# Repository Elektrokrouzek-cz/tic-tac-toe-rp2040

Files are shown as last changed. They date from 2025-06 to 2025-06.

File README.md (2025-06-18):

# Tic-tac-toe based on RP2040
This is the construction of tic-tac-toe game based on Raspberry Pi Pico (RP2040). It consists of 3x3 game layout with Neopixel 5mm LEDs and buttons.

Code is written in Micropython

PCB is 2-layer and was designed using KiCad 9. Fabrication output for JLCPCB is in gerber folder.

**Happy coldering and coding**

Assembled PCB

Assembled PCB


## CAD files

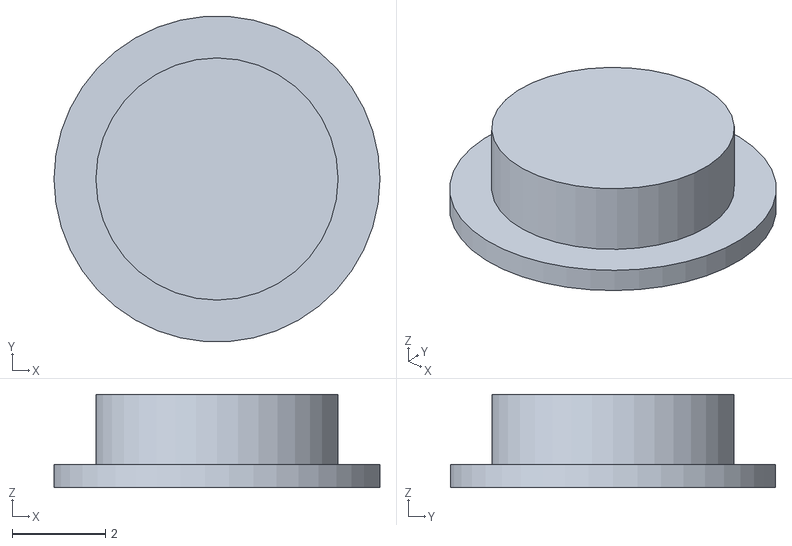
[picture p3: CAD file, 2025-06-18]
3d/tic_tac_toe_player_window.stl
7.00 x 6.98 x 2.00

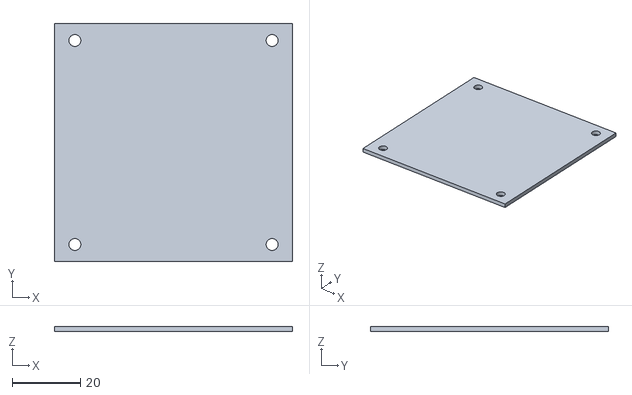
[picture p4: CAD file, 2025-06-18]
3d/tic_tac_toe_back_cover.stl
70.0 x 70.0 x 1.60

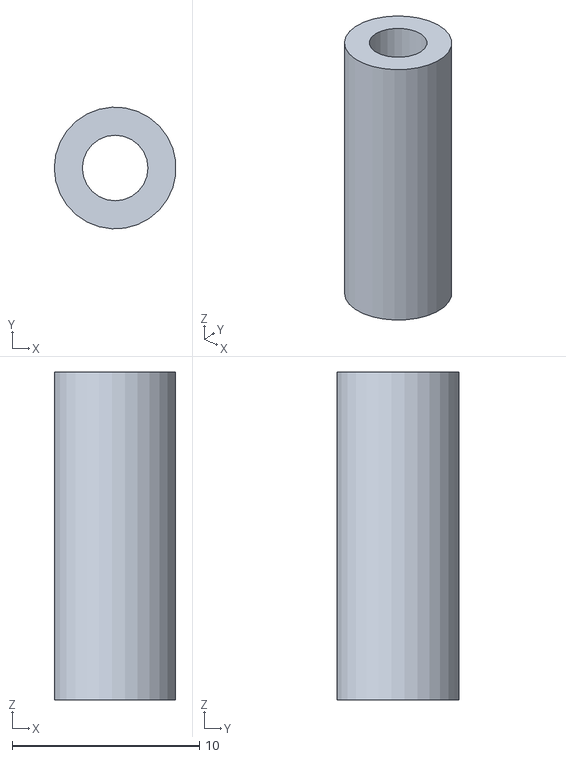
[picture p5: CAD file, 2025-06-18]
3d/tic_tac_toe_spacer.stl
6.48 x 6.49 x 17.5

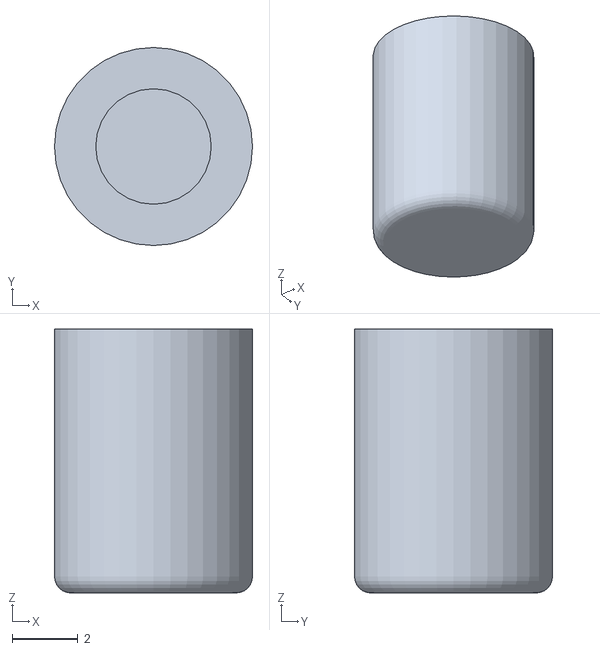
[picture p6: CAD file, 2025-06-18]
3d/tic_tac_toe_button.stl
6.00 x 6.00 x 8.00

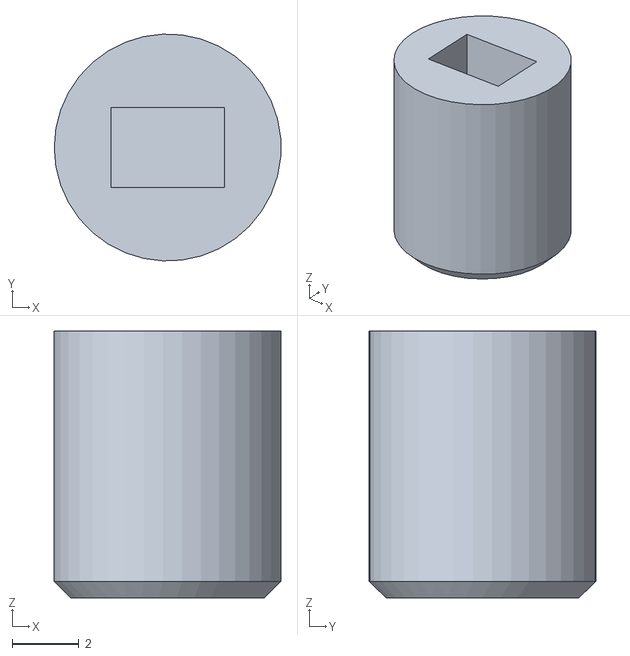
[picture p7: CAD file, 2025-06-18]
3d/tic_tac_toe_switch.stl
6.79 x 6.79 x 8.00

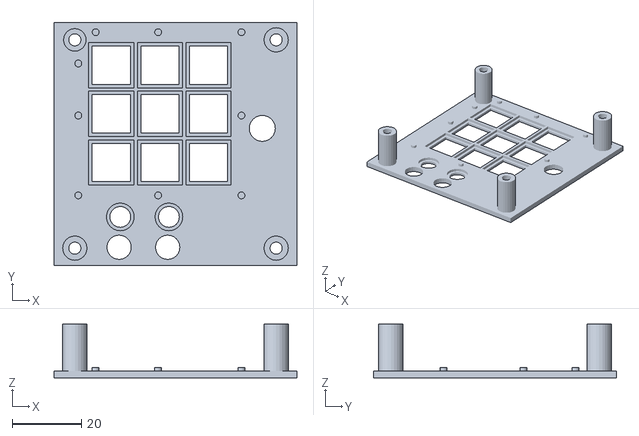
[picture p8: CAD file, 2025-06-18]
3d/tic_tac_toe_front_cover.stl
70.0 x 70.0 x 15.5

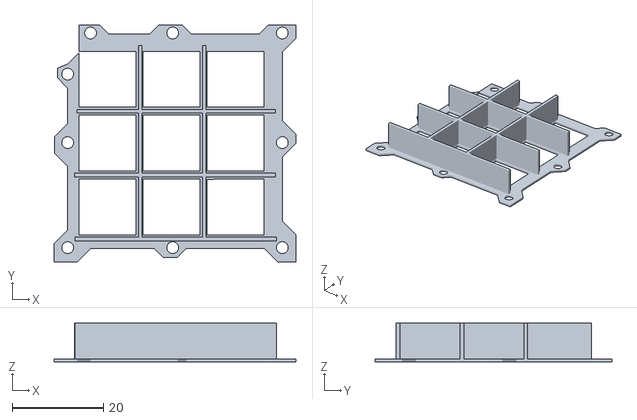
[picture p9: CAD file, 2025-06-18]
3d/tic_tac_toe_button_holder.stl
53.0 x 52.0 x 8.50

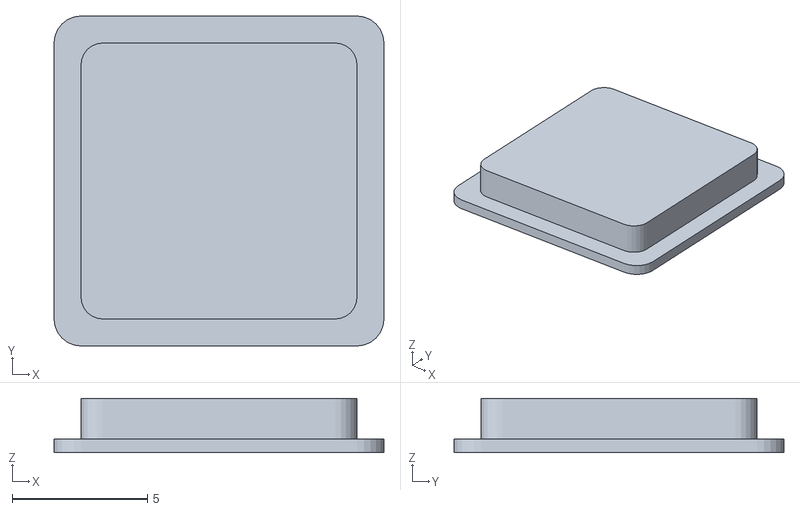
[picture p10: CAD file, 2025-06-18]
3d/tic_tac_toe_button_window.stl
12.2 x 12.2 x 2.00

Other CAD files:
3d/tic_tac_toe.f3d

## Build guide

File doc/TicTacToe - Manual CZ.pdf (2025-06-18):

www.elektrokrouzek.cz

## Piškvorky s RP2040

## Popis zapojení

Tato konstrukce je jednoduchá hra piškvorky, založená na Raspberry Pi Pico (RP2040 modul). Matice 3x3 Neopixel RGB LED diod, zapojených do řetězu, je připojena do GPIO0 pinu. Herní tlačítka jsou zapojena jako 3x3 matice se 3 sloupci and 3 řádky.
Další řetěz dvou Neopixel LED je zapojen do GPIO1 pinu. Dvě tlačítka pro volbu hráčů jsou zapojena do GPIO2 a GPIO3 pinů.
Hra může být napájena z USB nebo ze 4 AAA baterií. Je použit DC-DC step-down měnič pro vytvoření 5V napájení. Pro oddělení napájení USB od baterií je použita Schottkyho dioda.

## Popis sestavení

Začneme rezistory, dále Schottkyho diodou, RP2040 modulem a DC-DC step-down měničem. Následně osadíme tranzistor, LED diody, piezo, svorkovnici, tlačítka a vypínač.

## Oživení

Pokud jste pracovali pečlivě mělo by zapojení fungovat na první pokus. Je nutné do modulu RP2040 uložit firmware. Můžete použít např. Thonny IDE. Zdrojový kód je v git repozitáři.

## Seznam součástek

Annotation | Type | Qty
BZ1 | Passive buzzer | 1
D1,D2,D3,D4,D5,D6,D7,D8,D9,D10,D11 | APA-106-F5 | 11
D12 | BAT85 | 1
J1 | Screw terminal 3.5mm | 1
Q1 | BC546 | 1
R1 | 100k | 1
R2 | 10k | 1
SW1,SW2,SW3,SW4,SW5,SW6,SW7,SW8,SW9,SW10,SW11 | Turbo switch 7x7 | 11
SW12 | 7x7mm button | 1
U1 | WaveShare RP2040 | 1
U2 | DC-DC | 1

## Orientace vypínače a osazení desky

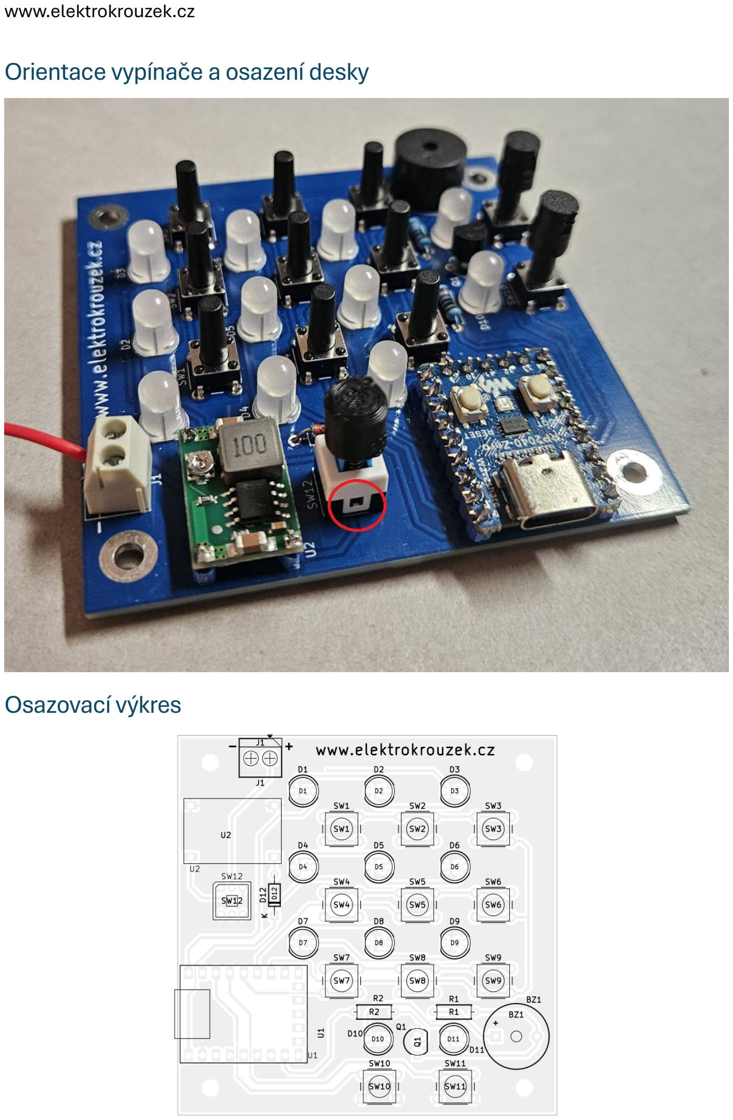
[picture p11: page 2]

## Osazovací výkres

## Mechanické sestavení

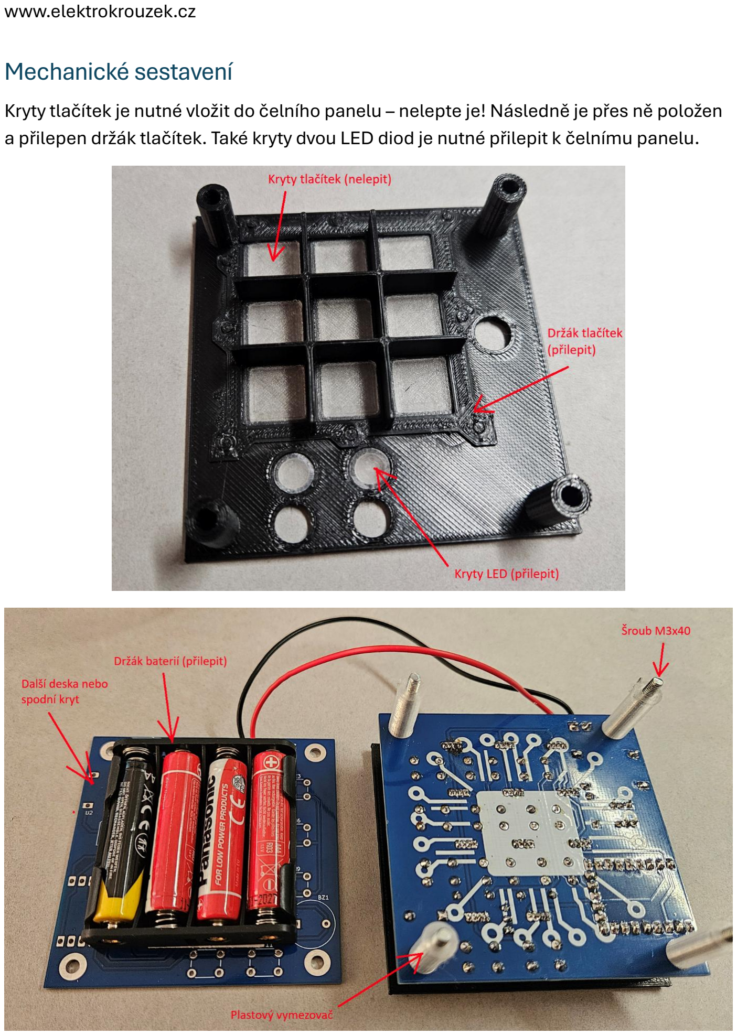
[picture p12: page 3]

Kryty tlačítek je nutné vložit do čelního panelu – nelepte je! Následně je přes ně položen a přilepen držák tlačítek. Také kryty dvou LED diod je nutné přilepit k čelnímu panelu.

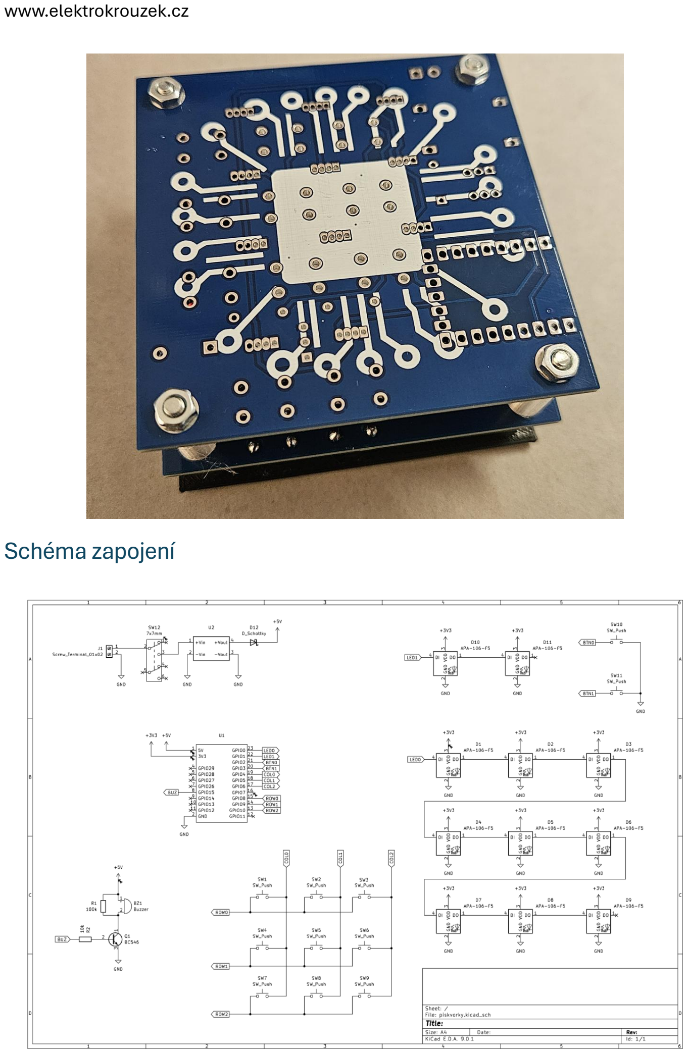
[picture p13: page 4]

## Schéma zapojení

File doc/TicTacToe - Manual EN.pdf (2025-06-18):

www.elektrokrouzek.cz

## Tic-tac-toe with RP2040

## Schematic description

This construction is the simple tic-tac-toe game based on Raspberry Pi Pico (RP2040 module). The matrix of 3x3 Neopixel RGB LED chain is connected to GPIO0 pin. Play buttons are connected as 3x3 matrix with 3 columns and 3 rows.
Another 2 Neopixel LED chain is connected to GPIO1 pin. 2 buttons for player selection are connected to GPIO2 and GPIO3 pins.
Game can be powered from USB or from 4 AAA batteries. DC-DC step-down is used to achieve 5V power supply. Schottky diode is used to separate USB and battery power supply.

## Construction

Resistors shall be populated first, then Schottky diode, RP2040 module and DC-DC step-down module. Then we populate transistor, LEDS, buzzer, terminal, buttons and power switch.

## How to get it into service

It should work on the first try when everything was soldered well. Firmware shall be saved to RP2040. You can use e.g. Thonny IDE. Source code can be found in git
repository.

## Bill of materials

Annotation | Type | Qty
BZ1 | Passive buzzer | 1
D1,D2,D3,D4,D5,D6,D7,D8,D9,D10,D11 | APA-106-F5 | 11
D12 | BAT85 | 1
J1 | Screw terminal 3.5mm | 1
Q1 | BC546 | 1
R1 | 100k | 1
R2 | 10k | 1
SW1,SW2,SW3,SW4,SW5,SW6,SW7,SW8,SW9,SW10,SW11 | Turbo switch 7x7 | 11
SW12 | 7x7mm button | 1
U1 | WaveShare RP2040 | 1
U2 | DC-DC | 1

## Button orientation and board assembly

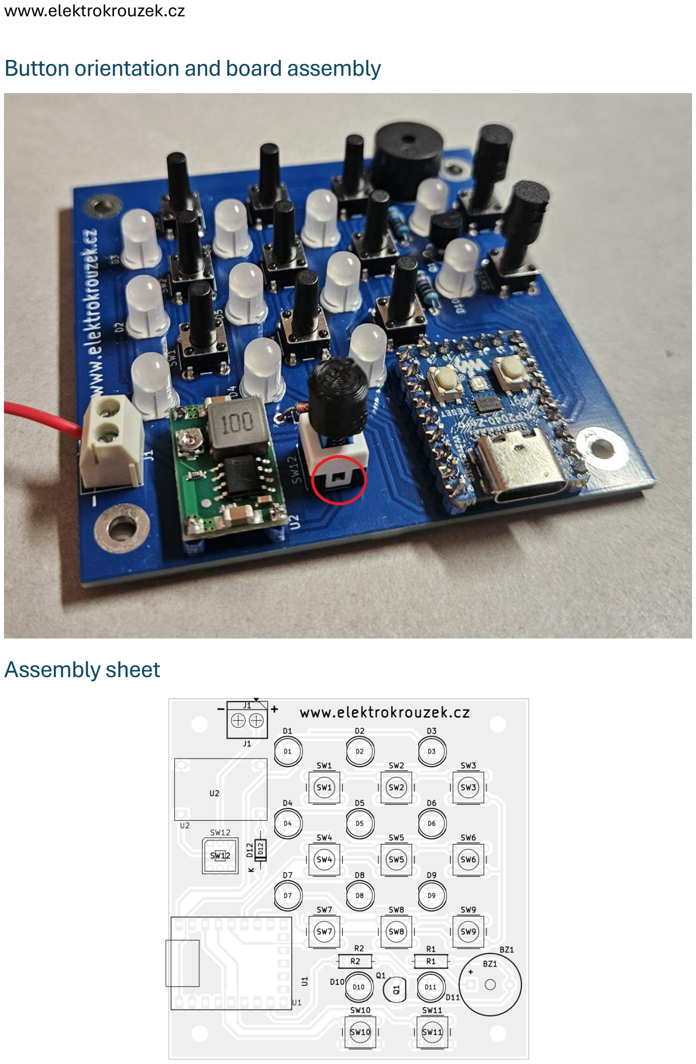
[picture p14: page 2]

## Assembly sheet

## Mechanical assembly

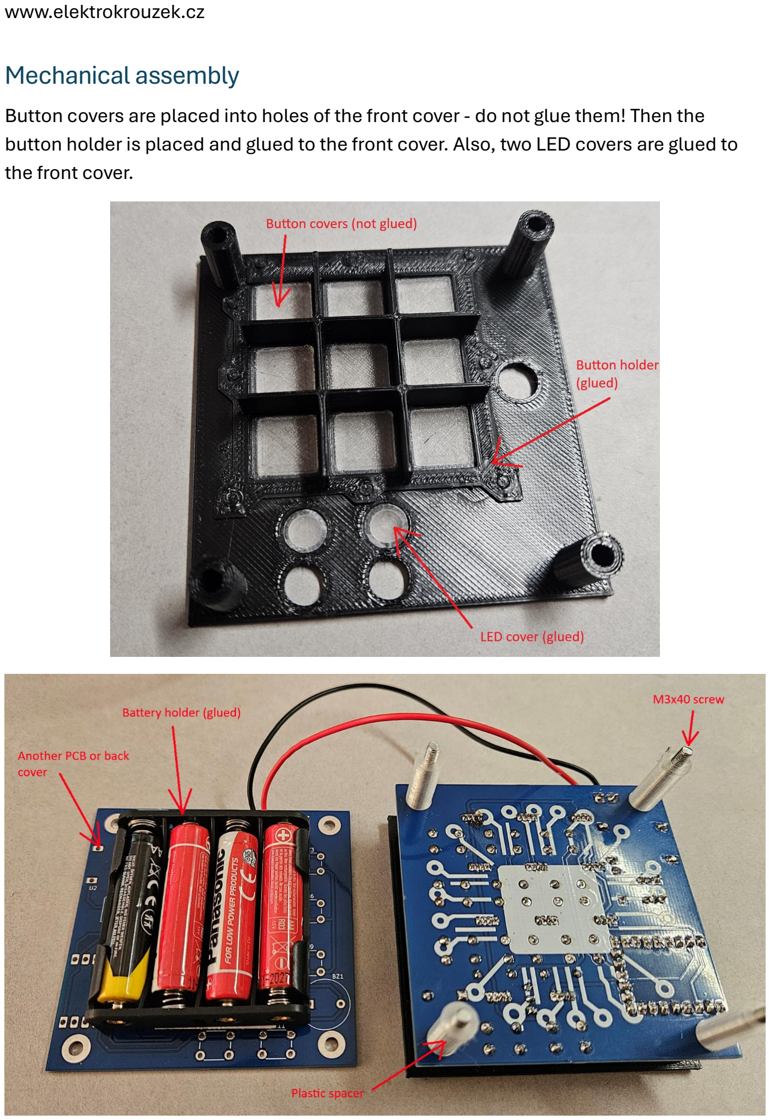
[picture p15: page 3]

Button covers are placed into holes of the front cover - do not glue them! Then the button holder is placed and glued to the front cover. Also, two LED covers are glued to the front cover.

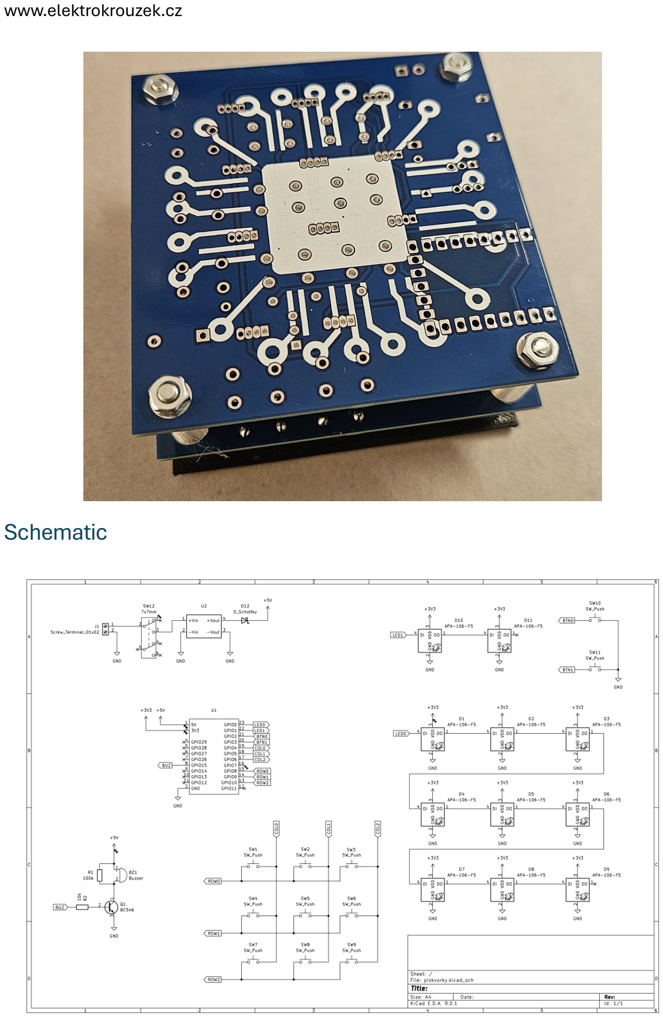
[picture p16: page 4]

## Schematic

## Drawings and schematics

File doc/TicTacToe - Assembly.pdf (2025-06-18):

1 | 2 | 3 | 4 | 5 | 6

A

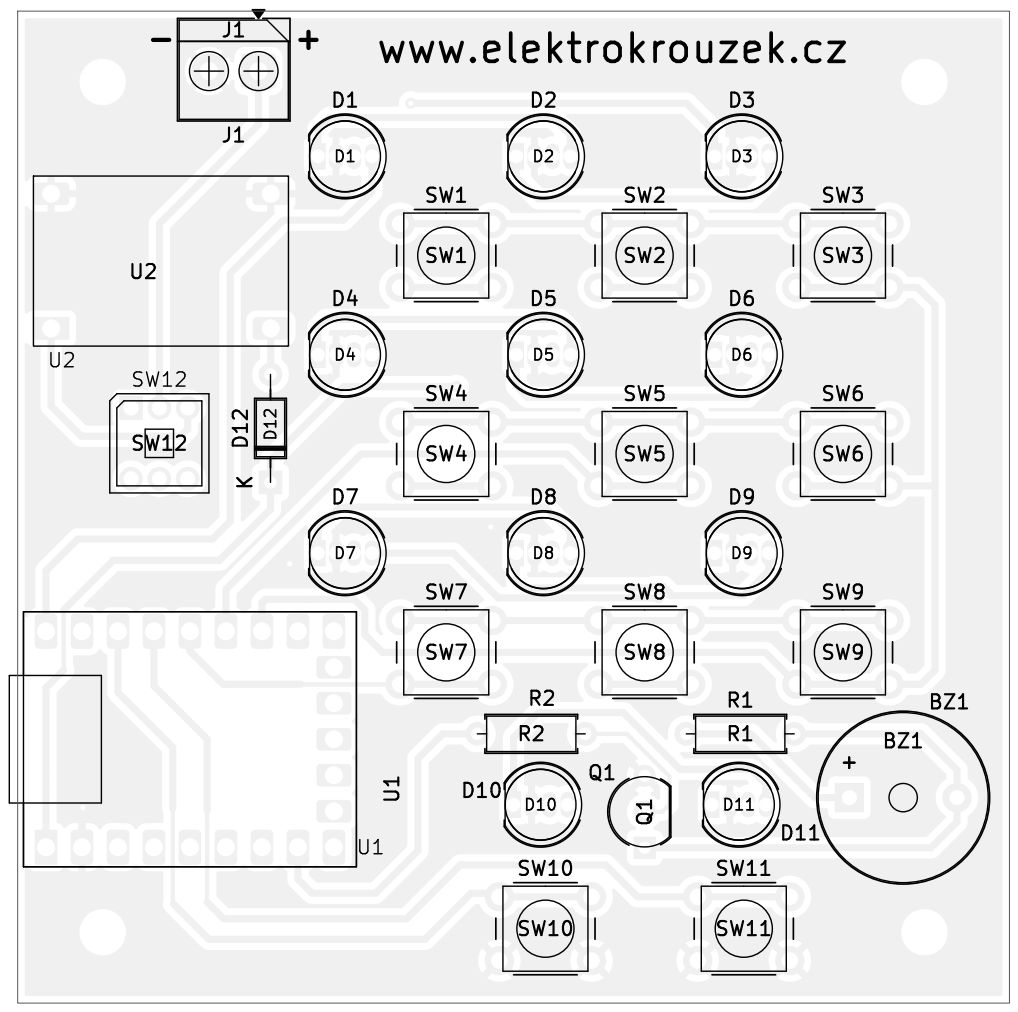
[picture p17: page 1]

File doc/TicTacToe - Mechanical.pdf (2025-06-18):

11.75 5.25 1 | 2 | 3 | 4 | 5 | 6

A

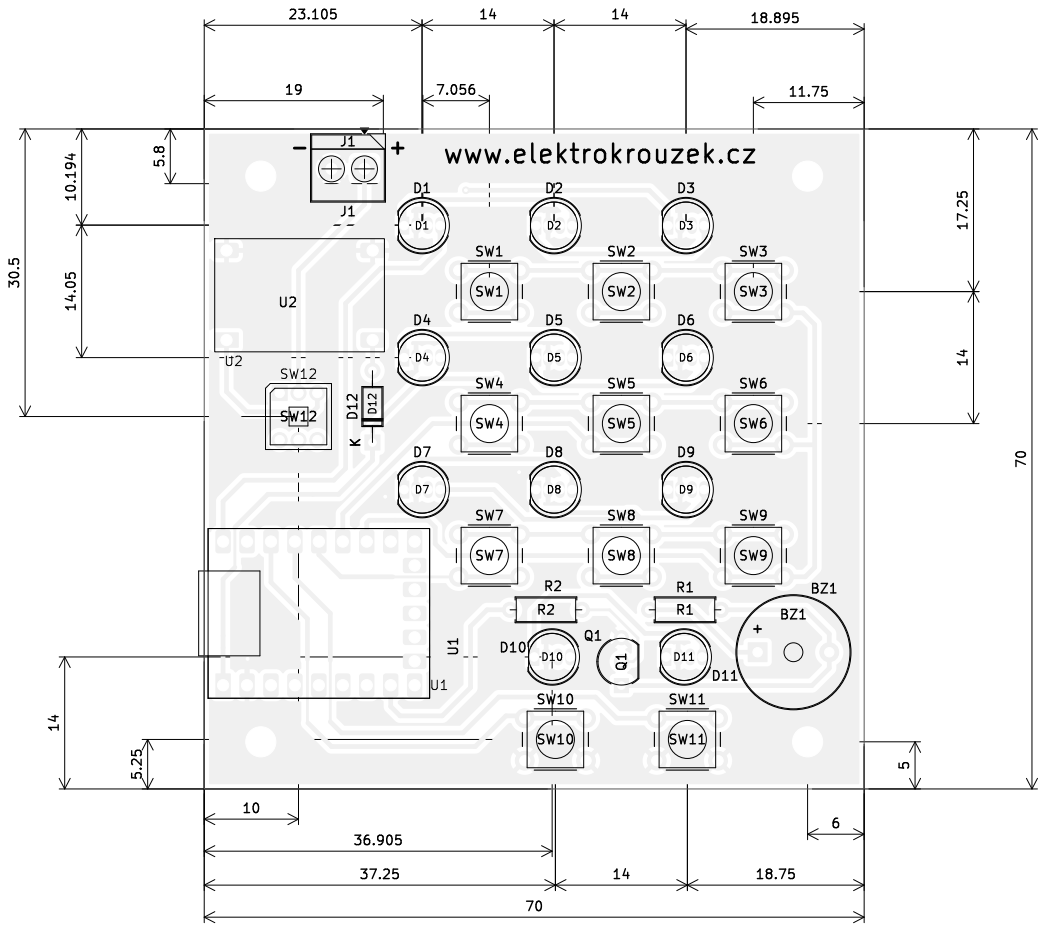
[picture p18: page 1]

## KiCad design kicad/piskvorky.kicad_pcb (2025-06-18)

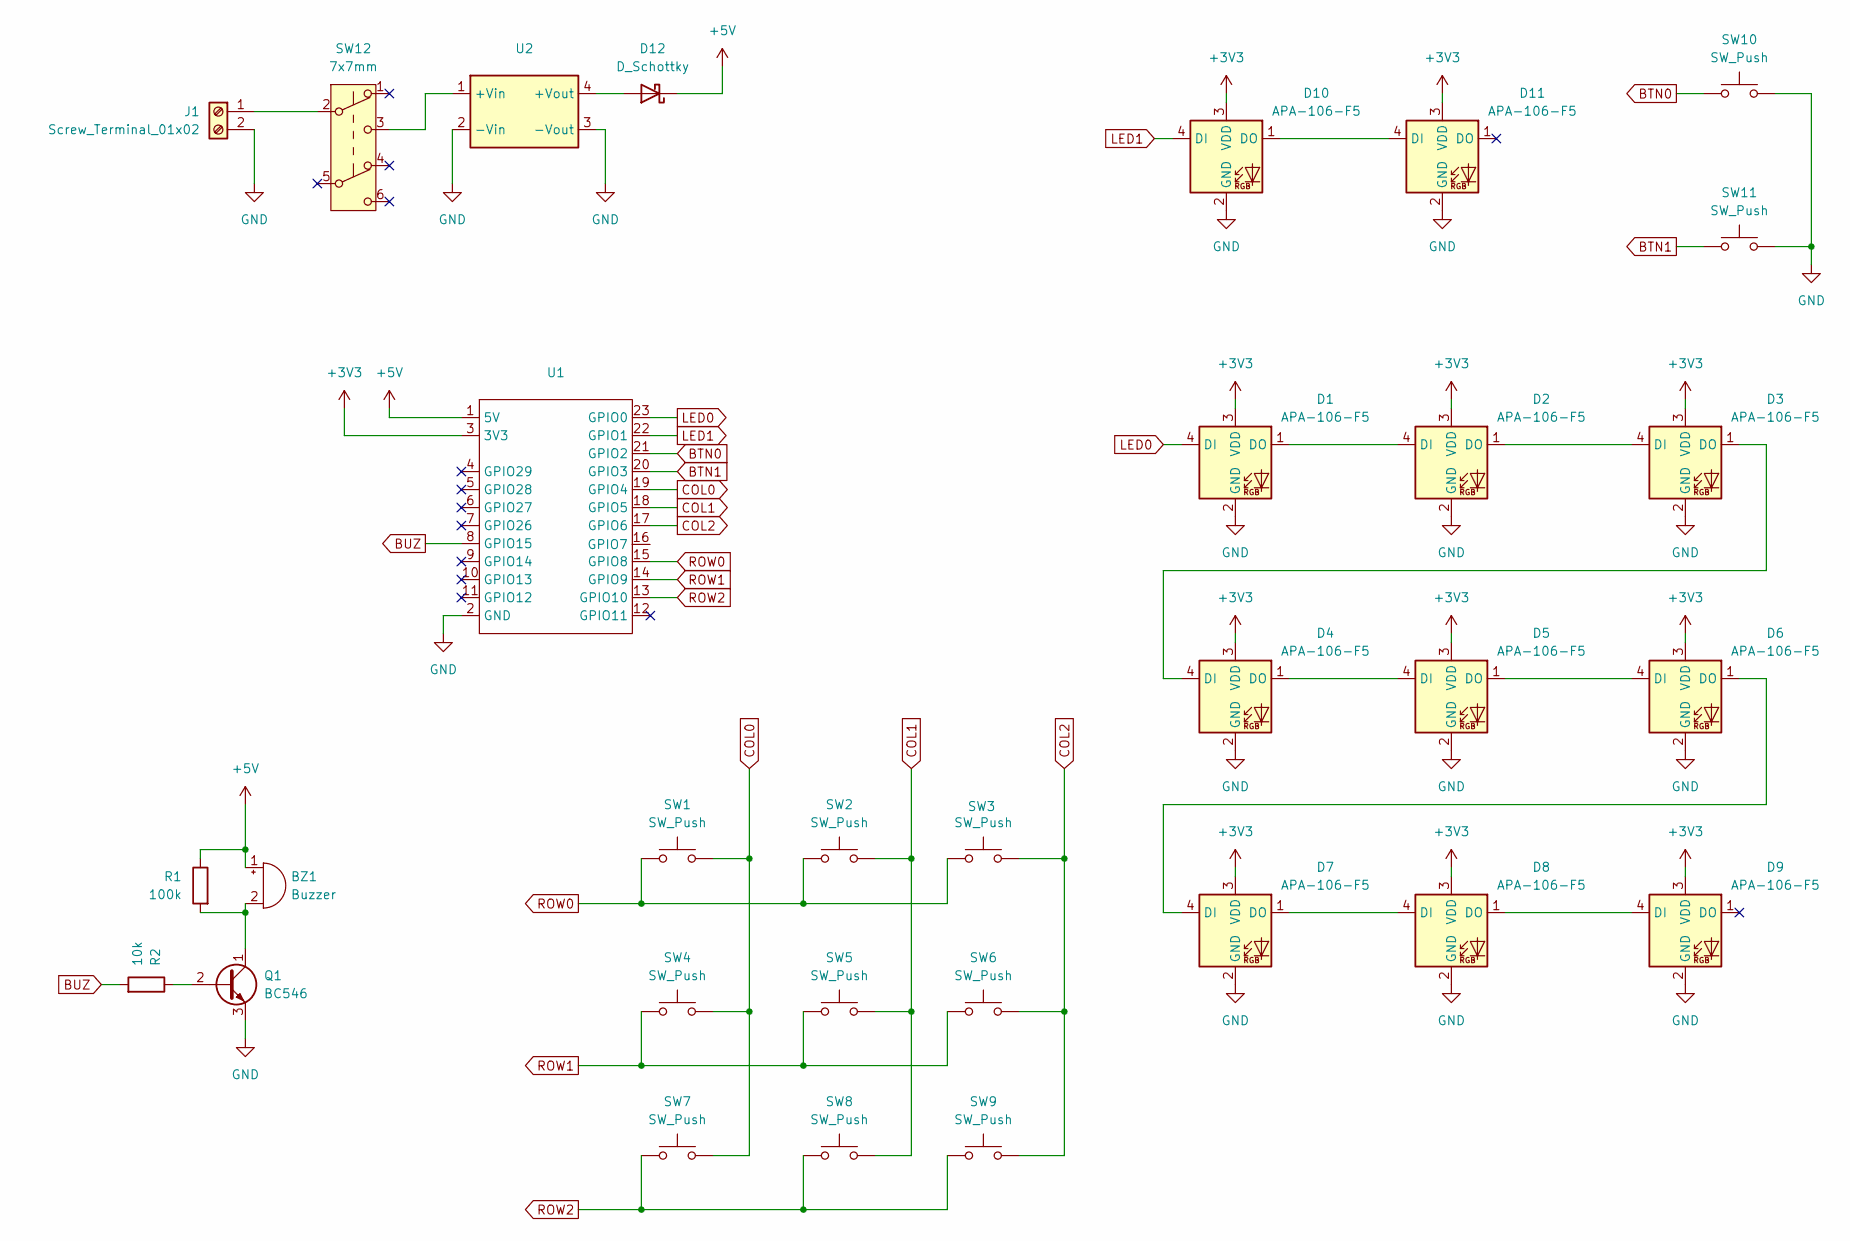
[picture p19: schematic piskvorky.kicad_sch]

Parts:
BZ1: Buzzer; Buzzer_12x9.5RM7.6
D1, D2, D3, D4, D5, D6, D7, D8, D9, D10, D11: APA-106-F5; LED_D5.0mm-4_RGB
D12: D_Schottky; D_DO-35_SOD27_P7.62mm_Horizontal
J1: Screw_Terminal_01x02; TerminalBlock_4Ucon_1x02_P3.50mm_Horizontal
Q1: BC546; TO-92_Inline_Wide
R1: 100k; R_Axial_DIN0207_L6.3mm_D2.5mm_P7.62mm_Horizontal
R2: 10k; R_Axial_DIN0207_L6.3mm_D2.5mm_P7.62mm_Horizontal
SW1, SW2, SW3, SW4, SW5, SW6, SW7, SW8, SW9, SW10, SW11: SW_Push; SW_PUSH_6mm_H5mm
SW12: 7x7mm; SW_DPDT_7x7_Turbo
U1: Waveshare RP2040
U2: DC-DC-18x12mm

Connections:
+3V3: D1.3 (VDD), D2.3 (VDD), D3.3 (VDD), D4.3 (VDD), D5.3 (VDD), D6.3 (VDD), D7.3 (VDD), D8.3 (VDD), D9.3 (VDD), D10.3 (VDD), D11.3 (VDD), U1.3 (3V3)
+5V: BZ1.1 (+), D12.1 (K), R1.1, U1.1 (5V)
BTN0: SW10.1, U1.21 (GPIO2)
BTN1: SW11.1, U1.20 (GPIO3)
BUZ: R2.2, U1.8 (GPIO15)
COL0: SW1.2, SW4.2, SW7.2, U1.19 (GPIO4)
COL1: SW2.2, SW5.2, SW8.2, U1.18 (GPIO5)
COL2: SW3.2, SW6.2, SW9.2, U1.17 (GPIO6)
GND: D1.2 (GND), D2.2 (GND), D3.2 (GND), D4.2 (GND), D5.2 (GND), D6.2 (GND), D7.2 (GND), D8.2 (GND), D9.2 (GND), D10.2 (GND), D11.2 (GND), J1.2, Q1.3 (E), SW10.2, SW11.2, U1.2 (GND), U2.2 (-Vin), U2.3 (-Vout)
LED0: D1.4 (DI), U1.23 (GPIO0)
LED1: D10.4 (DI), U1.22 (GPIO1)
unnamed: BZ1.2 (-), Q1.1 (C), R1.2
unnamed: D1.1 (DO), D2.4 (DI)
unnamed: D2.1 (DO), D3.4 (DI)
unnamed: D3.1 (DO), D4.4 (DI)
unnamed: D4.1 (DO), D5.4 (DI)
unnamed: D5.1 (DO), D6.4 (DI)
unnamed: D6.1 (DO), D7.4 (DI)
unnamed: D7.1 (DO), D8.4 (DI)
unnamed: D8.1 (DO), D9.4 (DI)
unnamed: D10.1 (DO), D11.4 (DI)
unnamed: D12.2 (A), U2.4 (+Vout)
unnamed: J1.1, SW12.2 (B)
unnamed: Q1.2 (B), R2.1
unnamed: SW12.3 (C), U2.1 (+Vin)
ROW0: SW1.1, SW2.1, SW3.1, U1.15 (GPIO8)
ROW1: SW4.1, SW5.1, SW6.1, U1.14 (GPIO9)
ROW2: SW7.1, SW8.1, SW9.1, U1.13 (GPIO10)

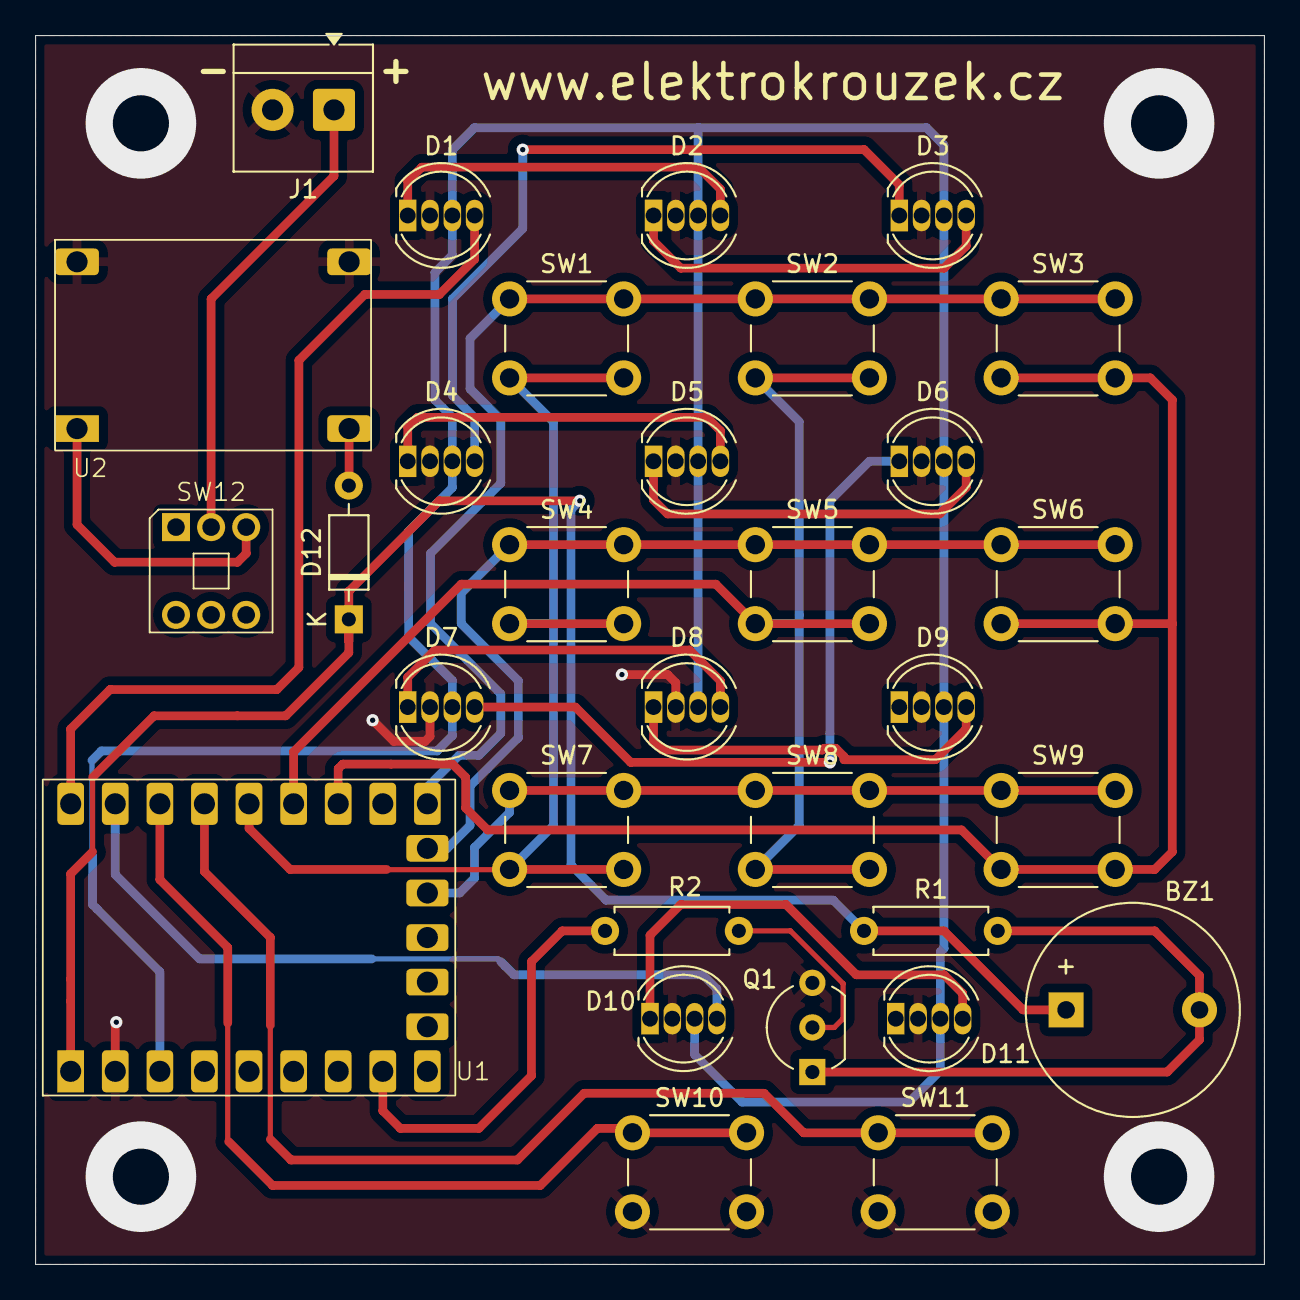
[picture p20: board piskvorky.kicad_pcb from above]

Board: 2 copper layers, 70.0 x 70.0 mm, 31 parts (0 on the bottom side), 28 nets.

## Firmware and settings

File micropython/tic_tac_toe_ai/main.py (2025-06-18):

import time
import machine, neopixel

WIDTH = 3
HEIGHT = 3

COLOR_NONE = 0
COLOR_RED = 1
COLOR_GREEN = 2
COLOR_BLUE = 3
COLOR_RED_REMOVE = 4
COLOR_GREEN_REMOVE = 5

COLOR_PLAYER1 = COLOR_RED
COLOR_PLAYER1_REMOVE = COLOR_RED_REMOVE
COLOR_PLAYER2 = COLOR_GREEN
COLOR_PLAYER2_REMOVE = COLOR_GREEN_REMOVE

KEY_DOWN_TIME = 0.05
    

class Screen:

    PROCESS_BLINK_PLAYER = 0
    PROCESS_BLINK_REMOVE = 1

    def __init__(self):
        self.__processesEnabled = [False, False]
        self.__processVariables = [None, None]
        self.__lastTimes = [0, 0]
        self.__lastStates = [0, 0]
        self.__np = neopixel.NeoPixel(machine.Pin(0), 9)
        self.__npPlayer = neopixel.NeoPixel(machine.Pin(1), 2)
        self.__colors = []
        for i in range(WIDTH * HEIGHT):
            self.__colors.append(COLOR_NONE)
        self.clear()
        self.update()
        self.setPlayer(False, False)
                
    def clear(self):
        for i in range(WIDTH * HEIGHT):
                self.__colors[i] = COLOR_NONE
        
    def update(self):
        for i in range(WIDTH * HEIGHT):
                self.__np[i] = self.__colorToRGB(self.__colors[i])
        self.__np.write()
        
    def setColor(self, x : int, y : int, color : int):
        self.__colors[x + y * WIDTH] = color
        
    def setPlayer(self, player1, player2):
        if player1:
            self.__npPlayer[0] = self.__colorToRGB(COLOR_PLAYER1)
        else:
            self.__npPlayer[0] = self.__colorToRGB(COLOR_NONE)
        if player2:
            self.__npPlayer[1] = self.__colorToRGB(COLOR_PLAYER2)
        else:
            self.__npPlayer[1] = self.__colorToRGB(COLOR_NONE)
        self.__npPlayer.write()

    def blinkScreen(self):
        colors = self.__colors.copy()
        for i in range(20):
            for i in range(len(self.__colors)):
                self.__colors[i] = COLOR_NONE
            screen.update()
            time.sleep(0.05)
            self.__colors = colors.copy()
            screen.update()
            time.sleep(0.05)

    def gameStop(self):
        self.clear()
        for i in range(WIDTH * HEIGHT):
            if i < 3:
                index = i
            elif i == 3:
                index = 5
            elif i < 7:
                index = 8 - i + 4
            elif i == 7:
                index = 3
            else:
                index = 4
            for ii in range(255 / 16):
                self.__np[index]= (0, 0, ii * 16)
                self.__np.write()
                time.sleep(0.01)

    def gameStart(self):
        self.clear()
        for ii in range(255 // 16, -1, -1):
            for i in range(WIDTH * HEIGHT):
                self.__np[i]= (0, 0, ii * 16)
            self.__np.write()
            time.sleep(0.01)

    def disableProcess(self, process):
        self.__processesEnabled[process] = False

    def enableProcess(self, process, variable):
        self.__processesEnabled[process] = True
        self.__processVariables[process] = variable
        self.__lastStates[process] = 0
        self.__lastTimes[process] = 0

    def process(self):
        t = time.ticks_ms()
        if self.__processesEnabled[Screen.PROCESS_BLINK_PLAYER]:
            if t - self.__lastTimes[Screen.PROCESS_BLINK_PLAYER] > 250:
                self.__lastTimes[Screen.PROCESS_BLINK_PLAYER] = t
                if self.__lastStates[Screen.PROCESS_BLINK_PLAYER] == 1:
                    self.setPlayer(self.__processVariables[Screen.PROCESS_BLINK_PLAYER] == 0, self.__processVariables[Screen.PROCESS_BLINK_PLAYER] == 1)
                    self.__lastStates[Screen.PROCESS_BLINK_PLAYER] = 0
                else:
                    self.setPlayer(False, False)
                    self.__lastStates[Screen.PROCESS_BLINK_PLAYER] = 1
        if self.__processesEnabled[Screen.PROCESS_BLINK_REMOVE]:
            if self.__lastStates[Screen.PROCESS_BLINK_REMOVE] == 0:
                for i in range(WIDTH * HEIGHT):
                    if self.__colors[i] == COLOR_PLAYER1_REMOVE:
                        self.__processVariables[Screen.PROCESS_BLINK_REMOVE] = (i, 0)
                        self.__lastStates[Screen.PROCESS_BLINK_REMOVE] = 1
                    elif self.__colors[i] == COLOR_PLAYER2_REMOVE:
                        self.__processVariables[Screen.PROCESS_BLINK_REMOVE] = (i, 1)
                        self.__lastStates[Screen.PROCESS_BLINK_REMOVE] = 1
            elif self.__lastStates[Screen.PROCESS_BLINK_REMOVE] == 1:
                if t - self.__lastTimes[Screen.PROCESS_BLINK_REMOVE] > 250:
                    color = COLOR_PLAYER1
                    if self.__processVariables[Screen.PROCESS_BLINK_REMOVE][1] == 1:
                        color = COLOR_PLAYER2
                    self.__colors[self.__processVariables[Screen.PROCESS_BLINK_REMOVE][0]] = color
                    self.update()
                    self.__lastStates[Screen.PROCESS_BLINK_REMOVE] = 2
            elif self.__lastStates[Screen.PROCESS_BLINK_REMOVE] == 2:
                if t - self.__lastTimes[Screen.PROCESS_BLINK_REMOVE] > 250:
                    color = COLOR_PLAYER1_REMOVE
                    if self.__processVariables[Screen.PROCESS_BLINK_REMOVE][1] == 1:
                        color = COLOR_PLAYER2_REMOVE
                    self.__colors[self.__processVariables[Screen.PROCESS_BLINK_REMOVE][0]] = color
                    self.update()
                    self.__lastStates[Screen.PROCESS_BLINK_REMOVE] = 1

    def __colorToRGB(self, color : int):
        if color == COLOR_NONE:
            return (0, 0, 0)
        if color == COLOR_RED:
            return (0, 255, 0)
        if color == COLOR_GREEN:
            return (255, 0, 0)
        if color == COLOR_BLUE:
            return (0, 0, 255)
        if color == COLOR_RED_REMOVE:
            return (0, 20, 0)
        if color == COLOR_GREEN_REMOVE:
            return (20, 0, 0)
        return (0, 0, 0)
    
class Keyboard:
    
    def __init__(self):
        self.__pinRows = []
        self.__pinRows.append(machine.Pin(8, machine.Pin.OUT))
        self.__pinRows.append(machine.Pin(9, machine.Pin.OUT))
        self.__pinRows.append(machine.Pin(10, machine.Pin.OUT))
        for y in range(HEIGHT):
            self.__pinRows[y].high()
        self.__pinCols = []
        self.__pinCols.append(machine.Pin(4, machine.Pin.IN, machine.Pin.PULL_UP))
        self.__pinCols.append(machine.Pin(5, machine.Pin.IN, machine.Pin.PULL_UP))
        self.__pinCols.append(machine.Pin(6, machine.Pin.IN, machine.Pin.PULL_UP))
        self.__player1Key = machine.Pin(2, machine.Pin.IN, machine.Pin.PULL_UP)
        self.__player2Key = machine.Pin(3, machine.Pin.IN, machine.Pin.PULL_UP)
        self.__player1KeyDownTimestamp = 0
        self.__player2KeyDownTimestamp = 0
        self.__player1KeyDown = False
        self.__player2KeyDown = False
        
    def getKeyPressed(self):
        for y in range(HEIGHT):
            self.__pinRows[y].low()
            time.sleep(0.02)
            for x in range(WIDTH):
                if self.__pinCols[x].value() == 0:
                    self.__pinRows[y].high()
                    return x, y
            self.__pinRows[y].high()
            time.sleep(0.02)
        return -1, -1
    
    def getPlayerKeyPressed(self):
        t = time.ticks_ms()
        if self.__player1Key.value() == 0:
            if (t - self.__player1KeyDownTimestamp > 0.2) and not self.__player1KeyDown:
                self.__player1KeyDownTimestamp = t
                self.__player1KeyDown = True
                return 0
        else:
            self.__player1KeyDownTimestamp = 0
            self.__player1KeyDown = False
        if self.__player2Key.value() == 0:
            if (t - self.__player2KeyDownTimestamp > 0.2) and not self.__player2KeyDown:
                self.__player2KeyDownTimestamp = t
                self.__player2KeyDown = True
                return 1
        else:
            self.__player2KeyDownTimestamp = 0
            self.__player2KeyDown = False
        return -1
    
class Sound:
    
    def __init__(self):
        self.__pwm = machine.PWM(machine.Pin(15), duty_u16=0)
        self.__pwm.init(freq=2000, duty_u16=0)
        
    def playMove(self, player):
        if player == 0:
            self.__pwm.freq(2500)
        else:
            self.__pwm.freq(3000)
        self.__pwm.duty_u16(32768)
        time.sleep(0.1)
        self.__pwm.duty_u16(0)

    def playSelect(self):
        self.__pwm.freq(2500)
        self.__pwm.duty_u16(32768)
        time.sleep(0.08)
        self.__pwm.freq(3000)
        self.__pwm.duty_u16(32768)
        time.sleep(0.08)
        self.__pwm.duty_u16(0)      

    def playBadMove(self):
        self.__pwm.freq(500)
        for i in range(20):
            self.__pwm.duty_u16(32768)
            time.sleep(0.01)
            self.__pwm.duty_u16(0)
            time.sleep(0.01)

class Game:
    
    HISTORY_SIZE = 7
    MAX_AI_DEPTH = 4

    def __init__(self, screen):
        self.__screen = screen
        self.__playerColors = []
        self.__playerColors.append(COLOR_RED)
        self.__playerColors.append(COLOR_GREEN)
        self.__playground = []
        self.__history = []
        self.clear()
        
    def clear(self):
        self.__playground.clear()
        for i in range(WIDTH * HEIGHT):
            self.__playground.append(-1)
        self.__history.clear()
        self.__screen.clear()
        self.__screen.update()
                
    def getPlayer(self, x, y):
        return self.__getPlayer(x, y, self.__playground)
                
    def getWinner(self):
        winner, kind = self.__getWin(self.__playground)
        return winner
    
    def isPlaygroundFull(self):
        return -1 not in self.__playground
        
    def blinkWinner(self):
        winner, kind = self.__getWin(self.__playground)
        for i in range(20):
            self.__setWinColor(kind, 0)
            time.sleep(0.05)
            self.__setWinColor(kind, self.__playerColors[winner])
            time.sleep(0.05)

    def putPlayer(self, x, y, player):
        self.__putPlayer(y * WIDTH + x, player, self.__playground, self.__history)
        self.__screen.setColor(x, y, self.__playerColors[player])
        self.__screen.update()
        
    def checkHistory(self):
        if len(self.__history) >= Game.HISTORY_SIZE:
            x = self.__history[0][1] % WIDTH
            y = self.__history[0][1] // WIDTH
            player = self.__history[0][0]
            self.__playground[y * WIDTH + x] = -1
            self.__history.pop(0)        
            for i in range(5):
                self.__screen.setColor(x, y, COLOR_NONE)
                self.__screen.update()
                time.sleep(0.05)
                self.__screen.setColor(x, y, self.__playerColors[player])
                self.__screen.update()
                time.sleep(0.05)
            self.__screen.setColor(x, y, COLOR_NONE)
            self.__screen.update()
        if len(self.__history) == Game.HISTORY_SIZE - 1:
            x = self.__history[0][1] % WIDTH
            y = self.__history[0][1] // WIDTH
            player = self.__history[0][0]
            color = COLOR_PLAYER1_REMOVE
            if player == 1:
                color = COLOR_PLAYER2_REMOVE
            self.__screen.setColor(x, y, color)
            self.__screen.update()

    def getBestMove(self, player):
        bestScore = float("-inf")
        bestMove = None
        playground = self.__playground.copy()
        history = self.__history.copy()

        moves = self.__availableMoves(playground)
        if len(moves) >= 7:
            maxDepth = 3
        else:
            maxDepth = Game.MAX_AI_DEPTH

        for move in self.__availableMoves(playground):
            # Make a calculating move
            playground[move] = player
            history.append((player, move))
            # Recursively call minimax with the next depth and the minimizing player
            score = self.__minimax(player, 0, maxDepth, False, playground.copy(), history.copy())
            # Reset the move
            playground[move] = -1
            history.pop()

            # Update the best score
            if score > bestScore:
                bestScore = score
                bestMove = move
        print("Best move for player {}: {}".format(player, bestMove))
        return bestMove
    
    def __minimax(self, player, depth, maxDepth, isMaximizing, playground, history):
        winner, kind = self.__getWin(playground)
        self.__screen.process()
        if winner == player:
            return 1 + maxDepth - depth
        if winner != -1:
            return -1 - maxDepth + depth
        if -1 not in playground:
            return 0
        
        if depth >= maxDepth:
            return 0

        if len(self.__history) >= Game.HISTORY_SIZE:
            index = self.__history[0][1]
            player = self.__history[0][0]
            playground[index] = -1
            history.pop(0)

        nextPlayer = player + 1
        if nextPlayer > 1:
            nextPlayer = 0

        # if it is the maximizing player's turn (AI), we want to maximize the score
        if isMaximizing:
            bestScore = float("-inf")
            for index in self.__availableMoves(playground):
                # Make a calculating move
                playground[index] = player
                history.append((player, index))
                # Recursively call minimax with the next depth and the minimizing player
                score = self.__minimax(player, depth + 1, maxDepth, False, playground.copy(), history.copy())
                # Reset the move
                playground[index] = -1
                history.pop()
                # Update the best score
                bestScore = max(score, bestScore)
            return bestScore
        else:
            # if it is the minimizing player's turn (human), we want to minimize the score
            bestScore = float("inf")
            for move in self.__availableMoves(playground):
                # Make a calculating move
                playground[move] = nextPlayer
                history.append((nextPlayer, move))
                # Recursively call minimax with the next depth and the maximizing player
                score = self.__minimax(player, depth + 1, maxDepth, True, playground.copy(), history.copy())
                # Reset the move
                playground[move] = -1
                history.pop()
                # Update the best score
                bestScore = min(score, bestScore)
            return bestScore
        
    def __availableMoves(self, playground):
        return [i for i, player in enumerate(playground) if player == -1]

    def __putPlayer(self, index, player, playground, history):
        history.append((player, index))
        playground[index] = player

    def __setWinColor(self, kind, color):
        if kind < 3:
            self.__screen.setColor(0, kind, color)
            self.__screen.setColor(1, kind, color)
            self.__screen.setColor(2, kind, color)
            self.__screen.update()
        elif kind < 6:
            self.__screen.setColor(kind - 3, 0, color)
            self.__screen.setColor(kind - 3, 1, color)
            self.__screen.setColor(kind - 3, 2, color)
            self.__screen.update()
        elif kind == 6:
            self.__screen.setColor(0, 0, color)
            self.__screen.setColor(1, 1, color)
            self.__screen.setColor(2, 2, color)
            self.__screen.update()
        elif kind == 7:
            self.__screen.setColor(0, 2, color)
            self.__screen.setColor(1, 1, color)
            self.__screen.setColor(2, 0, color)
            self.__screen.update()
        
    @staticmethod
    def __getPlayer(x, y, playground):
        return playground[y * WIDTH + x]
            
    def __getWin(self, playground):
        for y in range(HEIGHT):
            p = self.__getPlayer(0, y, playground)
            if (p != -1) and (p == self.__getPlayer(1, y, playground)) and (p == self.__getPlayer(2, y, playground)):
                return p, y
        for x in range(WIDTH):
            p = self.__getPlayer(x, 0, playground)
            if (p != -1) and (p == self.__getPlayer(x, 1, playground)) and (p == self.__getPlayer(x, 2, playground)):
                return p, 3 + x
        p = self.__getPlayer(0, 0, playground)
        if (p != -1) and (p == self.__getPlayer(1, 1, playground)) and (p == self.__getPlayer(2, 2, playground)):
            return p, 6
        p = self.__getPlayer(0, 2, playground)
        if (p != -1) and (p == self.__getPlayer(1, 1, playground)) and (p == self.__getPlayer(2, 0, playground)):
            return p, 7
        return -1, -1
        
screen = Screen()
keyboard = Keyboard()
sound = Sound()
game = Game(screen)
screen.update()

player = 0
playerChanged = True

aiPlayer = -1
finished = False

screen.gameStop()

while True:

    screen.disableProcess(Screen.PROCESS_BLINK_PLAYER)
    screen.disableProcess(Screen.PROCESS_BLINK_REMOVE)
    screen.setPlayer(not aiPlayer == 0, not aiPlayer == 1)

    while True:
        x, y = keyboard.getKeyPressed()
        if (x != -1) and (y != -1):
            screen.setPlayer(False, False)
            screen.gameStart()
            break
        playerKey = keyboard.getPlayerKeyPressed()
        if playerKey == 0:
            if aiPlayer == -1:
                aiPlayer = 0
                screen.setPlayer(False, True)
            elif aiPlayer == 0:
                aiPlayer = -1
                screen.setPlayer(True, True)
            sound.playSelect()
        if playerKey == 1:
            if aiPlayer == -1:
                aiPlayer = 1
                screen.setPlayer(True, False)
            elif aiPlayer == 1:
                aiPlayer = -1
                screen.setPlayer(True, True)
            sound.playSelect()

    game.clear()
    player = 0
    finished = False
    playerChanged = True

    while not finished:
        screen.process()

        if playerChanged:
            screen.setPlayer(player == 0, player == 1)
            if player == aiPlayer:
                screen.enableProcess(Screen.PROCESS_BLINK_PLAYER, player)
            else:
                screen.disableProcess(Screen.PROCESS_BLINK_PLAYER)
            time.sleep(0.2)
            playerChanged = False

        processWinner = False
        if player == aiPlayer:
            t = time.ticks_ms()
            print("AI is thinking...")
            bestMove = game.getBestMove(player)
            while time.ticks_ms() - t < 2000:
                screen.process()
            if bestMove is not None:
                game.putPlayer(bestMove % WIDTH, bestMove // WIDTH, player)
                sound.playMove(player)
                processWinner = True
        playerKey = keyboard.getPlayerKeyPressed()
        if playerKey != -1:
            sound.playSelect()
            screen.gameStop()
            finished = True
        x, y = keyboard.getKeyPressed()
        if (x != -1) and (y != -1):
            if game.getPlayer(x, y) == -1:
                game.putPlayer(x, y, player)
                sound.playMove(player)
                processWinner = True
            else:
                sound.playBadMove()
        if processWinner:
            winner = game.getWinner()
            if winner != -1:
                print("Player {} wins".format(winner))
                game.blinkWinner()
                screen.gameStop()
                finished = True
            else:
                if game.isPlaygroundFull():
                    print("It's a tie!")
                    screen.blinkScreen()
                    screen.gameStop()
                    finished = True
                else:
                    screen.disableProcess(Screen.PROCESS_BLINK_REMOVE)
                    game.checkHistory()
                    screen.enableProcess(Screen.PROCESS_BLINK_REMOVE, 0)
                    player += 1
                    if player > 1:
                        player = 0
                    playerChanged = True
                

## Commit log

2025-04-10 Kicad libraries added
2025-06-18 Documentation added
    [piskvorky-B_Cu.gbl, piskvorky-B_Mask.gbs, piskvorky-B_Paste.gbp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]
